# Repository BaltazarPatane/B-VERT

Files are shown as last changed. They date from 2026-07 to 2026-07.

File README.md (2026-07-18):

<h1 align="center">B-VERT</h1>

<h3 align="center">Medidor portátil de salto vertical</h3>

<p align="center">
  <strong>Electrónica embebida · Medición ultrasónica · Diseño e impresión 3D</strong>
</p>

<p align="center">
  
  
  
  
</p>

&emsp; 

<p align="center">
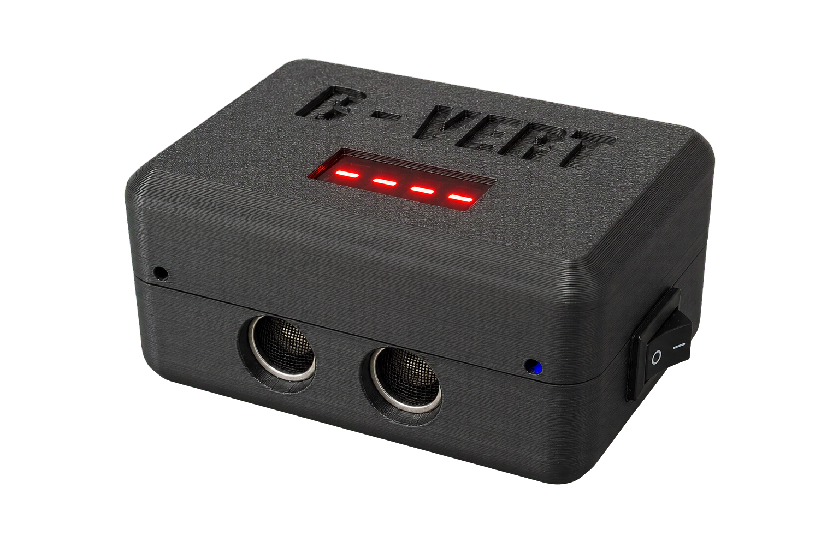
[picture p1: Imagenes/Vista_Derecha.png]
Vista derecha de B-VERT
  
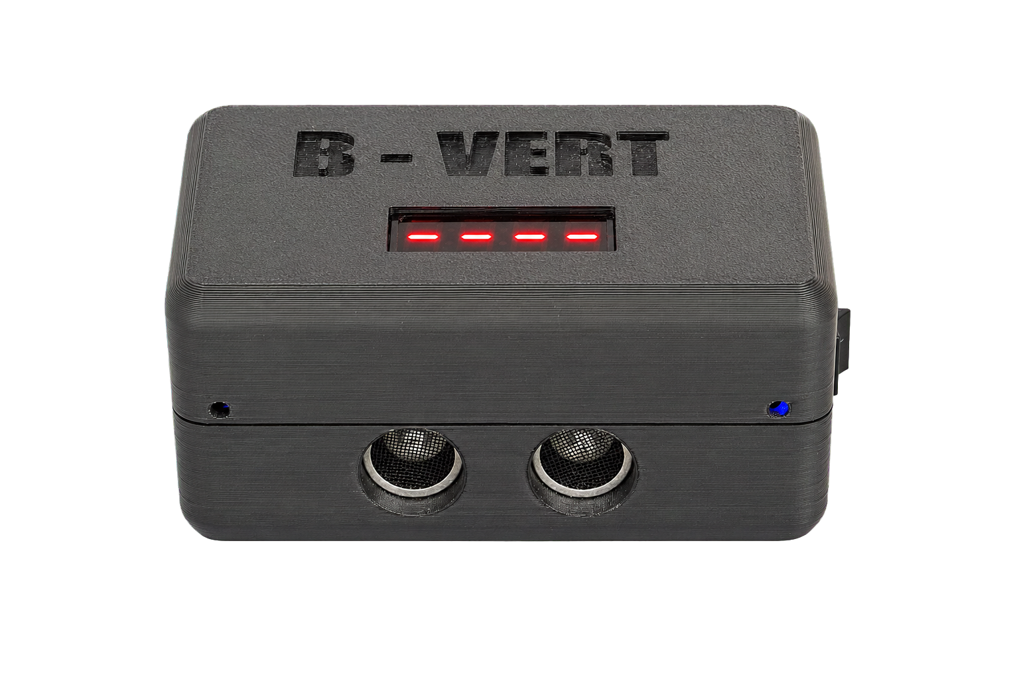
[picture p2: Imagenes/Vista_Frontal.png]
Vista frontal de B-VERT
  
</p>

## Descripción general

&emsp; **B-VERT** es un sistema electrónico portátil diseñado para medir la altura de un salto vertical de manera automática y sin contacto. Un sensor ultrasónico detecta el despegue y el aterrizaje del usuario, mientras que un **Arduino Nano** procesa el tiempo total de vuelo y calcula la altura alcanzada. El resultado se presenta inmediatamente en un display de cuatro dígitos y se acompaña con señales sonoras que indican las distintas etapas de la medición. El firmware utiliza una **máquina de estados**, medición por **interrupciones** y múltiples validaciones para distinguir un salto real de lecturas aisladas o erróneas. El proyecto integra electrónica, programación de sistemas embebidos, modelado CAD y fabricación mediante impresión 3D en un único dispositivo compacto.

> La lógica de B-VERT no toma decisiones a partir de una sola lectura: cada transición importante debe cumplir condiciones temporales y acumular mediciones consecutivas coherentes.

&emsp; 

## Componentes electrónicos

| Componente | Función dentro del sistema |
| --- | --- |
| **Arduino Nano** | Ejecuta la máquina de estados, procesa las mediciones y calcula la altura. |
| **HC-SR04** | Detecta la presencia o ausencia del usuario mediante ultrasonido. |
| **Display TM1637** | Muestra indicaciones, animaciones y la altura calculada. |
| **Membrana piezoeléctrica pasiva** | Genera las señales sonoras de inicio y finalización. |
| **Interruptor general** | Conecta o interrumpe la alimentación del dispositivo. |
| **Power bank de 5 V** | Proporciona una fuente de energía portátil y recargable. |
| **Placa experimental y cableado** | Interconectan y distribuyen la alimentación entre los módulos. |

&emsp; 

## Diagrama de conexiones

<p align="center">
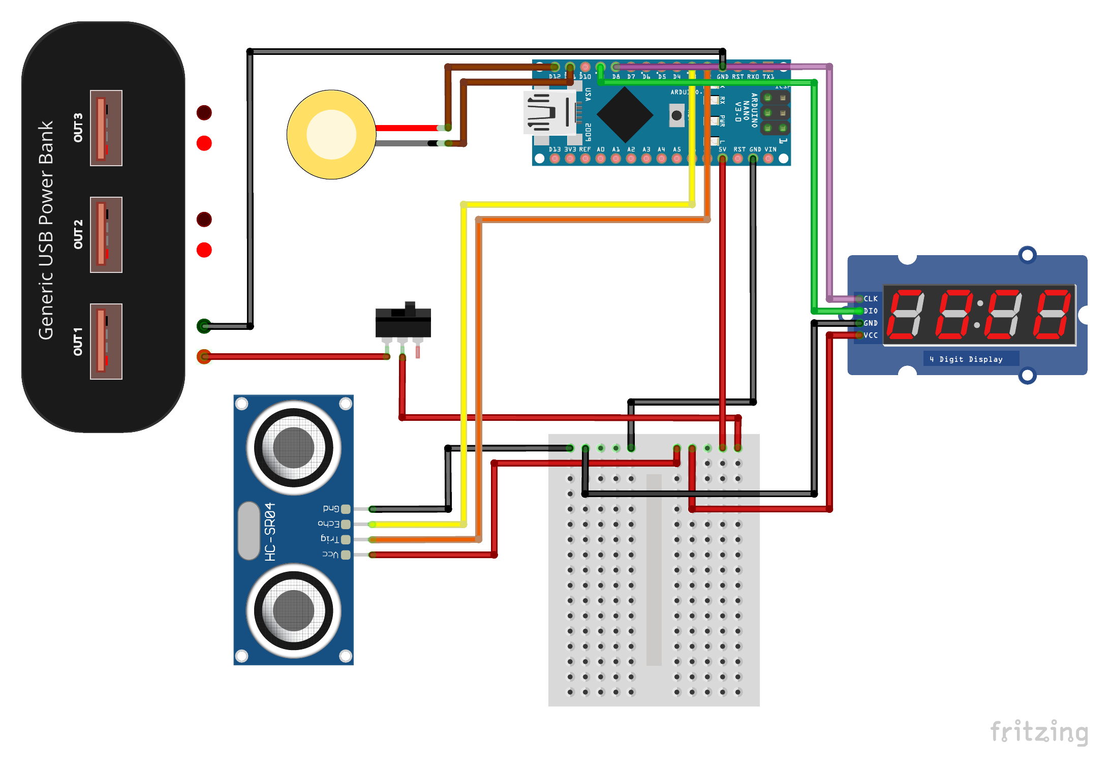
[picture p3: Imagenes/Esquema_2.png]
Diagrama de conexiones de B-VERT
  
</p>

La documentación del hardware se encuentra disponible en los siguientes formatos:

- [Ver esquema eléctrico en PDF](Hardware/Esquema_B-VERT.pdf)
- [Abrir el proyecto editable de Fritzing](Hardware/Esquema_B-VERT.fzz)

&emsp; 

## Diseño mecánico e impresión 3D

&emsp; La carcasa de B-VERT fue modelada en **Autodesk Fusion 360** y fabricada mediante impresión 3D. Su froma consiste en una caja rectangular compacta de bordes y esquinas redondeados, pensada para proteger la electrónica y facilitar el transporte y la manipulación del equipo.

&emsp; El diseño está dividido de forma horizontal en dos tapas encastrables. Además, en la cara frontal se incorporaron dos aberturas circulares para el emisor y el receptor del HC-SR04, manteniendo los transductores expuestos sin dejar desprotegido el resto del circuito La superficie superior incluye un corte rectangular para el display de cuatro dígitos y el nombre **B-VERT** integrado en la propia pieza, mientras que en uno de los laterales se agregó el recorte para el interruptor de encendido y apagado.

&emsp; 

<p align="center">
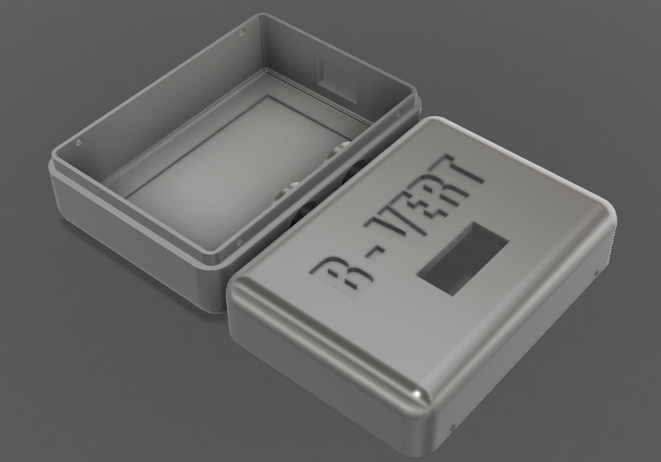
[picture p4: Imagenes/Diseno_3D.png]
Diseño 3D de la carcasa B-VERT
  
</p>

&emsp; 

## Funcionamiento

&emsp; Al encenderse, B-VERT ejecuta una etapa de inicialización en la que comprueba que el sensor entregue valores válidos y que la persona esté ubicada dentro del rango previsto. Una vez completada esta verificación, el display indica que el equipo está listo y una señal sonora habilita el inicio del salto. Desde ese momento, el sensor ultrasónico realiza mediciones periódicas y el firmware analiza la continuidad de esas lecturas.

&emsp; El despegue no se confirma ante una única pérdida de señal. El sistema exige una secuencia sostenida de mediciones que indiquen la ausencia de la persona y conserva el instante de la primera lectura válida de esa secuencia como comienzo del vuelo. De forma equivalente, el aterrizaje solo se acepta cuando varias lecturas consecutivas vuelven a confirmar su presencia. Esta estrategia evita que un rebote, una reflexión deficiente o un pulso aislado del sensor sean interpretados como un salto completo.

&emsp; Cuando se confirma el aterrizaje, el tiempo transcurrido entre ambos eventos se utiliza para calcular la altura. El resultado final se muestra en el display y se acompaña con un aviso sonoro; luego de un breve intervalo, el sistema reinicia automáticamente el ciclo y queda preparado para una nueva medición.

&emsp; La altura se obtiene mediante la ecuación del movimiento vertical (donde **$t$** es el tiempo total de vuelo y **$g$** es la aceleración de la gravedad):

$$
h = \frac{g \cdot t^2}{8}
$$

&emsp; 

### Máquina de estados

| Estado | Responsabilidad |
| --- | --- |
| **`REINICIANDO`** | Restablece variables y contadores, ejecuta la animación inicial y valida la posición del usuario. |
| **`LISTO`** | Supervisa las mediciones y espera una ausencia sostenida que permita confirmar el despegue. |
| **`CONTANDO`** | Cronometra el tiempo de vuelo, actualiza la estimación en pantalla y espera la confirmación del aterrizaje. |
| **`TERMINADO`** | Calcula y muestra la altura definitiva, reproduce el aviso sonoro y prepara un nuevo ciclo. |

> Esta separación hace que el comportamiento sea **determinista y fácil de mantener**
&emsp; 

### Medición mediante interrupciones

&emsp; Durante el funcionamiento normal, la duración del pulso `ECHO` del HC-SR04 se captura mediante una **interrupción por cambio de estado** en el pin D3. En el flanco ascendente, la rutina registra el instante de inicio y en el flanco descendente, calcula la duración total del pulso y marca la disponibilidad de una nueva medición. De esta manera, el microcontrolador puede continuar atendiendo la máquina de estados, el display y las señales sonoras sin permanecer bloqueado esperando la respuesta del sensor.

&emsp; Las variables compartidas entre la interrupción y el programa principal se declaran como `volatile`. Además, el firmware deshabilita brevemente las interrupciones al copiar o reiniciar esos datos, creando secciones críticas que evitan lecturas parciales o inconsistentes.

##

<p align="center">
  Proyecto diseñado y desarrollado por <strong>Baltazar Patané</strong>.
</p>

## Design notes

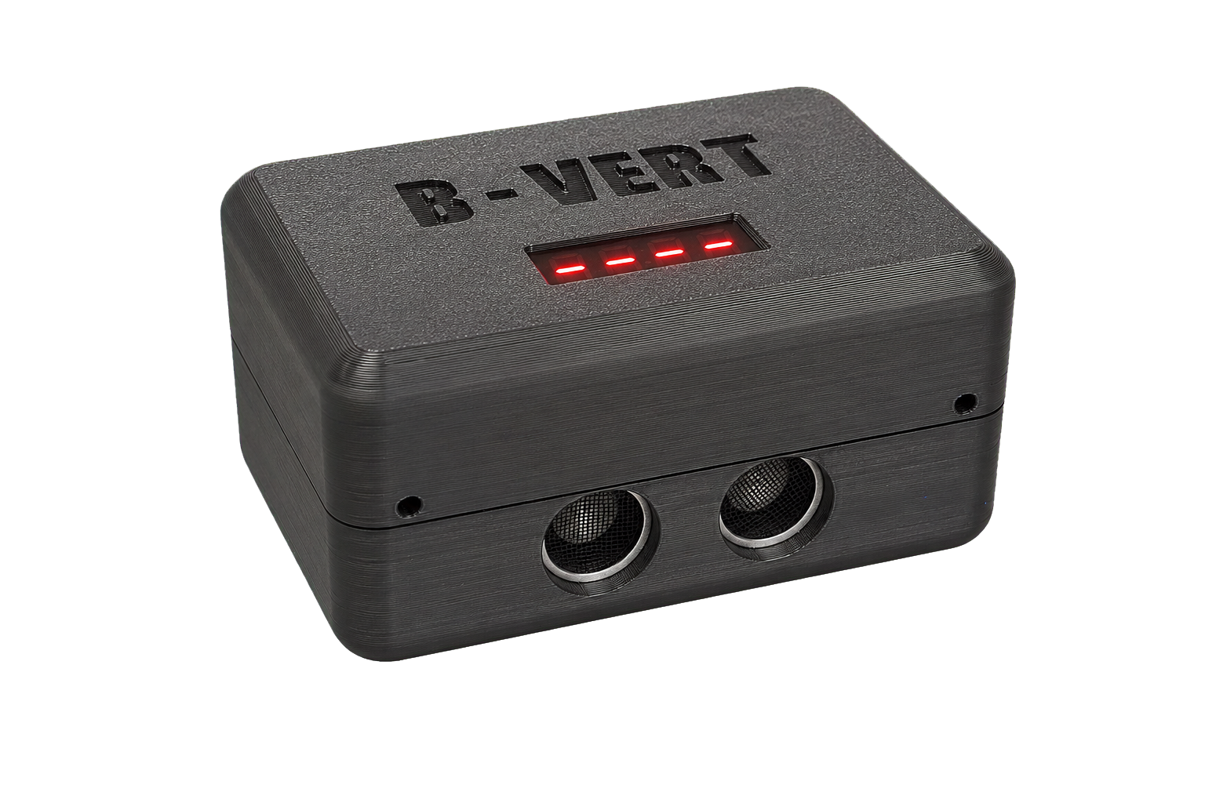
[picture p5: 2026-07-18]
Imagenes/Vista_Izquierda.png

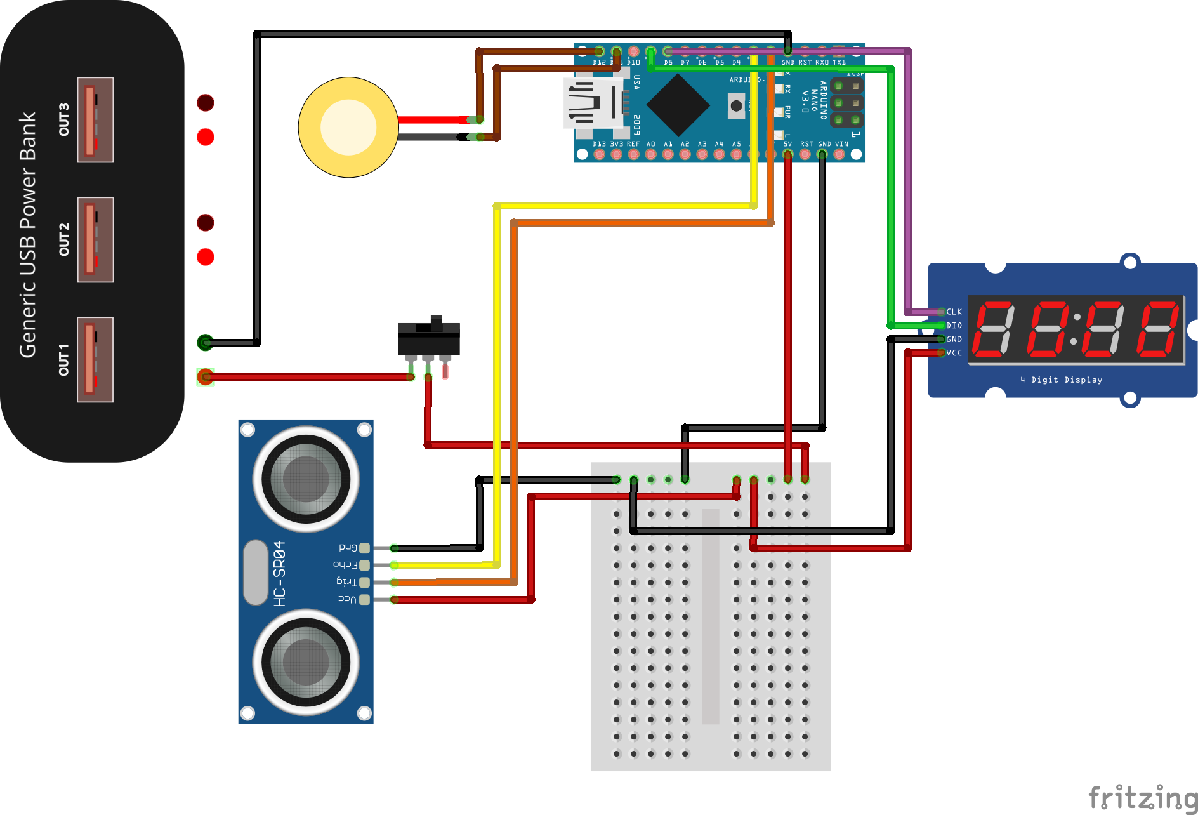
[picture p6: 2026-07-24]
Imagenes/Esquema.png

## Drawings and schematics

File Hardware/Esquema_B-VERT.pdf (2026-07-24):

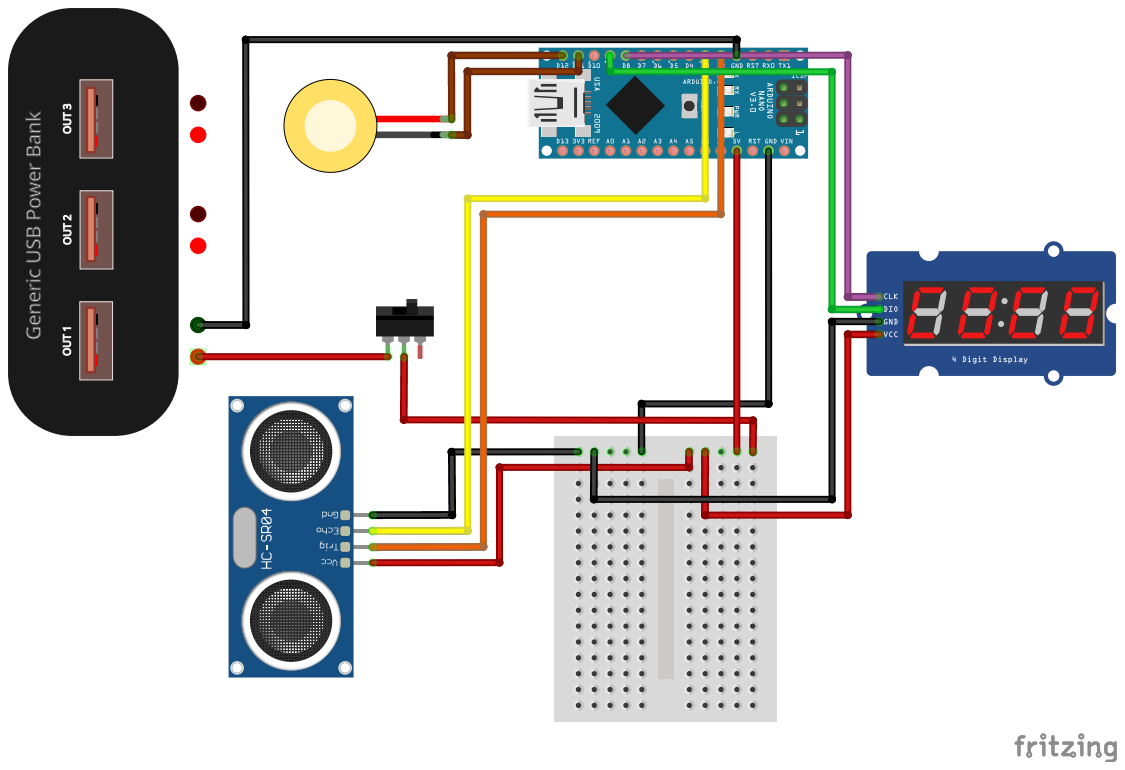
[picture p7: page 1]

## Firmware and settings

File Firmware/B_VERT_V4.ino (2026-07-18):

#include <Arduino.h>
#include <TM1637Display.h>

#define TRIG 2
#define ECHO 3
#define DIO 8
#define CLK 9
#define BEEPA 11
#define BEEPB 12

#define FPS 20000UL
#define demasiado_lejos 3000UL // Tiempo mínimo que debe durar el pulso para considerar que la persona está en el aire, en microsegundos
#define dist_min 300UL // Tiempo mínimo que debe durar el pulso para considerar que no es un rebote interno, en microsegundos
#define muestras_para_salto 20
#define muestras_para_caida 2
#define muestras_para_informar muestras_para_caida
//#define cinco_cm_salto 300UL // Tiempo mínimo que debe durar el salto para evitar errores grandes, en microsegundos
//#define tiempo_presencia_ausencia 10000UL // Tiempo que debe pasar para considerar que la persona saltó o aterrizó, en microsegundos

typedef enum {
    REINICIANDO,
    LISTO,
    CONTANDO,
    TERMINADO
} maquina_estados;

const uint8_t JUMP[] = {
    SEG_D | SEG_E | SEG_B | SEG_C,
    SEG_D | SEG_E | SEG_B | SEG_C | SEG_F,
    SEG_A | SEG_E | SEG_B | SEG_C | SEG_F,
    SEG_A | SEG_E | SEG_B | SEG_G | SEG_F,
};

const uint8_t GUION[] = {SEG_G, SEG_G, SEG_G, SEG_G};

const uint8_t A[] = {SEG_A, SEG_A, SEG_A, SEG_A};
const uint8_t B[] = {SEG_B, SEG_B, SEG_B, SEG_B};
const uint8_t C[] = {SEG_C, SEG_C, SEG_C, SEG_C};
const uint8_t D[] = {SEG_D, SEG_D, SEG_D, SEG_D};
const uint8_t E[] = {SEG_E, SEG_E, SEG_E, SEG_E};
const uint8_t F[] = {SEG_F, SEG_F, SEG_F, SEG_F};

TM1637Display display(CLK, DIO);
volatile bool informar = true;
volatile bool esperando_eco = false;
volatile bool nueva_medicion = false;
volatile unsigned int chequeos = 0;
volatile unsigned int evil_chequeos_0 = 0;
volatile unsigned int evil_chequeos_999 = 0;
volatile unsigned long inicio_pulso = 0;
volatile unsigned long total_pulso = 0;
volatile unsigned long inicio_salto = 0;
volatile unsigned long inicio_ausencia = 0;
volatile unsigned long inicio_presencia = 0;
volatile unsigned int muestras_ausentes = 0;
volatile unsigned int muestras_presentes = 0;
volatile unsigned long total_salto = 0;
volatile unsigned long pulso_actual = 0;
volatile unsigned long inicio_pulso_actual = 0;
volatile unsigned long ultimo_disparo = 0;
volatile maquina_estados estado = REINICIANDO;

void carga() {
    for (int i = 1; i <= 3; i++) {
        display.setSegments(A); delay(100); display.setSegments(B); delay(100);
        display.setSegments(C); delay(100); display.setSegments(D); delay(100);
        display.setSegments(E); delay(100); display.setSegments(F); delay(100);
    }
    display.setSegments(GUION);
}

void inicializacion() {
    chequeos = 0;
    evil_chequeos_0 = 0;
    evil_chequeos_999 = 0;

    while (true) {
        // Envío pulso ultrasónico
        digitalWrite(TRIG, LOW); delayMicroseconds(2);
        digitalWrite(TRIG, HIGH); delayMicroseconds(10);
        digitalWrite(TRIG, LOW);

        // Espero respuesta del sensor o timeout
        unsigned long duracion = pulseIn(ECHO, HIGH, 30000L);

        float distancia = duracion * 0.034 / 2;
        Serial.println (distancia);

        if (duracion == 0) continue;

        // Si se encuentra a menos de 5cm no lo considero como una persona, sino como un error de medición
        if (duracion < dist_min) {
            chequeos = 0; evil_chequeos_999 = 0;
            if (evil_chequeos_0 > 2) {chequeos = 0; evil_chequeos_0 = 0;}
            else evil_chequeos_0++;
        }

        // Si se encuentra a más de 40cm no lo considero como una persona, sino como un error de medición
        else if (duracion > demasiado_lejos) {
            chequeos = 0; evil_chequeos_0 = 0;
            if (evil_chequeos_999 > 2) {chequeos = 0; evil_chequeos_999 = 0;}
            else evil_chequeos_999++;
        }

        // Si se encuentra entre 5cm y 40cm lo considero como una persona, y aumento el contador de chequeos
        else {chequeos++; evil_chequeos_0 = 0; evil_chequeos_999 = 0;}

        // Acumulo 3 chequeos por las dudas, para evitar falsos positivos por errores de medición
        if (chequeos > 0) break;
    }
}

void sonido_inicio() {
    for (int i = 0; i < 150; i++) {
        digitalWrite(BEEPA, HIGH); digitalWrite(BEEPB, LOW); delayMicroseconds(1500);
        digitalWrite(BEEPA, LOW); digitalWrite(BEEPB, HIGH); delayMicroseconds(1500);
    }
    digitalWrite(BEEPA, LOW); digitalWrite(BEEPB, LOW);
}

void sonido_final() {
    for (int j = 0; j < 2; j++) {
        for (int i = 0; i < 100; i++) {
            digitalWrite(BEEPA, HIGH); digitalWrite(BEEPB, LOW); delayMicroseconds(1000);
            digitalWrite(BEEPA, LOW); digitalWrite(BEEPB, HIGH); delayMicroseconds(1000);
        }
        digitalWrite(BEEPA, LOW); digitalWrite(BEEPB, LOW); delay(100);
    }
}

void informar_resultado(int total) {
    for (int i = 1; i < 4; i++) {
        display.showNumberDecEx(total, false); delay(500);
        display.clear(); delay(500);
    }
    display.showNumberDecEx(total, false); delay(3000); display.clear();
}

void sensor() {
    unsigned long ahora = micros();

    if (digitalRead(ECHO) == HIGH) {
        inicio_pulso = ahora; // Si ECHO está en HIGH es porque se envío el pulso ultrasónico, y se inicia la cuenta del tiempo que dura el pulso
        esperando_eco = true;
    }
    else {
        total_pulso = ahora - inicio_pulso; // Si ECHO está en LOW es porque se recibió el pulso ultrasónico, y se calcula el tiempo que duró el pulso
        
        float distancia = total_pulso * 0.034 / 2;
        Serial.println (distancia);

        esperando_eco = false;
        nueva_medicion = true;
    }
}

void setup() {
    pinMode(TRIG, OUTPUT);
    pinMode(ECHO, INPUT);
    pinMode(BEEPA, OUTPUT);
    pinMode(BEEPB, OUTPUT);

    display.setBrightness(4);

    attachInterrupt(digitalPinToInterrupt(ECHO), sensor, CHANGE);

    Serial.begin(250000);
}

void loop() {

    if (estado == REINICIANDO) {
        carga();

        inicializacion();

        display.setSegments(JUMP);

        sonido_inicio();

        estado = LISTO;

        noInterrupts();
        nueva_medicion = false;
        total_pulso = 0;
        inicio_pulso = 0;
        esperando_eco = false;
        ultimo_disparo = 0;
        interrupts();
    }

    if (esperando_eco && (micros() - inicio_pulso > FPS)) {
        noInterrupts();
        total_pulso = FPS;
        esperando_eco = false;
        nueva_medicion = true;
        interrupts();
    }

    if (nueva_medicion) {

        noInterrupts();
        pulso_actual = total_pulso;
        inicio_pulso_actual  = inicio_pulso;
        nueva_medicion = false;
        interrupts();

        //--------------------------------------------------------------------------------

        if ((estado != LISTO && estado != CONTANDO) || pulso_actual < dist_min) {
            inicio_ausencia = 0;
            inicio_presencia = 0;
            muestras_ausentes = 0;
            muestras_presentes = 0;
        } else {

            // Si no está contando y el pulso es muy largo, se comprueba si fue un salto
            if (estado != CONTANDO){
                if (pulso_actual > demasiado_lejos) {

                    if (muestras_ausentes == 0) {
                        inicio_ausencia = inicio_pulso_actual;
                    }

                    muestras_ausentes++;

                    if (muestras_ausentes >= muestras_para_salto) {
                        inicio_salto = inicio_ausencia;
                        inicio_ausencia = 0;
                        muestras_ausentes = 0;
                        muestras_presentes = 0;
                        estado = CONTANDO;
                    }

                } else {
                    inicio_ausencia = 0;
                    muestras_ausentes = 0;
                }
            }

            // Si está contando y el pulso es corto, se comprueba si fue una caída
            else if (estado == CONTANDO){
                if (pulso_actual < demasiado_lejos) {

                    if (muestras_presentes == 0) {
                        inicio_presencia = inicio_pulso_actual;
                        total_salto = inicio_presencia - inicio_salto;
                    }

                    muestras_presentes++;

                    if (muestras_presentes >= muestras_para_informar) {
                        informar = false;
                    }

                    if (muestras_presentes >= muestras_para_caida) {
                        total_salto = inicio_presencia - inicio_salto;
                        inicio_presencia = 0;
                        muestras_presentes = 0;
                        estado = TERMINADO;
                    }

                } else {
                    inicio_presencia = 0;
                    muestras_presentes = 0;
                    informar = true;
                }
            }
        }
    }
    //--------------------------------------------------------------------------------

    if (estado == CONTANDO && informar) {
        float t = (inicio_pulso_actual - inicio_salto) / 1000000.0;
        float altura = t * t * 9.80665 * 0.125 * 100; // t^2 * g * 1/8 * 100, altura en cm
        if (altura < 0) altura = 0;
        display.showNumberDec((unsigned int)altura);
    }

    if (estado == TERMINADO) {
        sonido_final();

        float t = total_salto / 1000000.0;            // total en microsegundos, t en segundos
        float altura = t * t * 9.80665 * 0.125 * 100; // t^2 * g * 1/8 * 100, altura en cm
        if (altura < 0) altura = 0;
        informar_resultado((unsigned int)altura);

        estado = REINICIANDO;
        inicio_ausencia = 0;
        inicio_presencia = 0;
        muestras_ausentes = 0;
        muestras_presentes = 0;
        informar = true;
        nueva_medicion = false;
        esperando_eco = false;
        ultimo_disparo = 0;
    }

    if (!esperando_eco && (micros() - ultimo_disparo > FPS)) {

        ultimo_disparo = micros();

        noInterrupts();
        inicio_pulso = ultimo_disparo;
        esperando_eco = true;
        interrupts();

        digitalWrite(TRIG, LOW);
        delayMicroseconds(2);
        digitalWrite(TRIG, HIGH);
        delayMicroseconds(10);
        digitalWrite(TRIG, LOW);
    }
}
